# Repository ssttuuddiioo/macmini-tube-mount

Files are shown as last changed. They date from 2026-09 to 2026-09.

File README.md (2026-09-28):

# Mac mini tube mount

A 3D-printable cradle that clamps a Mac mini (127 × 127 × 50 mm) to a 1" (25.4 mm) square tube whose bottom face is velcroed down.
- **Tube velcroed down:** the Mac sits upside-down on top of it, centered, with its vented foot facing up and open.
- **Vertical tube:** the Mac hangs front-up, with the back-panel cables pointing down.

The clamp grips only the tube's two side faces, so nothing wraps around the velcro face. A small lip on the fixed side hooks 2.5 mm over one edge. Four zip-tie eyes at the corners, beside the tube, let you tie the cradle down as well; they take standard 4.8 mm ties. Four parts, all printed in PETG, with no metal hardware and no supports.

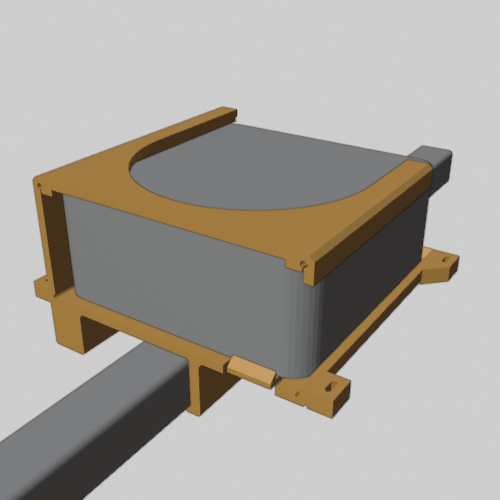
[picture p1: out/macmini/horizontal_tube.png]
Sitting on the velcroed tube


## Print

The STLs in `out/macmini/stl/` are already in print orientation, sitting on Z = 0. They were sized for a Bambu P1S (256 mm bed).

| File | Color in renders | Print orientation | Settings |
|---|---|---|---|
| `cradle.stl` | orange | front face down | 4 walls, 35% infill, brim |
| `nut.stl` | green | thread vertical | 100% infill |
| `screw_4a.stl` | yellow | wheel down | 100% infill |
| `pad.stl` | purple | grip face down | 100% infill |

Or open the ready-made plates in `out/macmini/plates/`. Each object's name lists its settings:
- `plate1_test_pieces.3mf`: the nut, a short screw stub and a 10 mm slice of the clamp. Print this first to check the thread and the tube fit. If they fit, keep the nut as a spare.
- `plate2_parts.3mf`: all four parts on one 256 mm bed.

## Assemble

1. Slide the Mac into the cradle from the front until the roof tab clicks over its front edge. The back lip stops it at the rear.
2. Drop the nut into its slot from the back of the cradle, sliding it down to the middle.
3. Thread screw 4a in from the side, through the wall and the nut, until its tip comes out on the inside. Snap the pad onto the tip.
4. Back the screw off. Hook the fixed jaw's lip under one edge of the tube, lower the cradle onto it, and tighten the screw until the pad grips the tube.
5. Optionally, run zip ties through the corner eyes to whatever the tube is mounted on.

## Rebuild from source

The geometry comes from one Blender script (tested on Blender 5.2):

```bash
blender -b --factory-startup --python build_macmini_mount.py
```

It rebuilds every part, checks fits and printability and that nothing reaches the tube's velcro face, and writes the STLs, plates and renders to `out/macmini/`. Dimensions are constants at the top of the script. For example, `RAD_CL` sets the thread clearance and `LIP_REACH` the lip size.

[NOTES_macmini.md](NOTES_macmini.md) lists the design decisions, the measured clearances, and the open issues. Check the ones about your Mac, your tube and your velcro before printing everything.

## Views

| Vertical tube | Exploded |
|---|---|
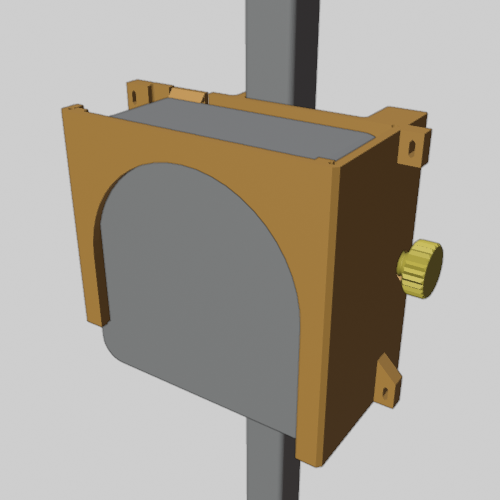
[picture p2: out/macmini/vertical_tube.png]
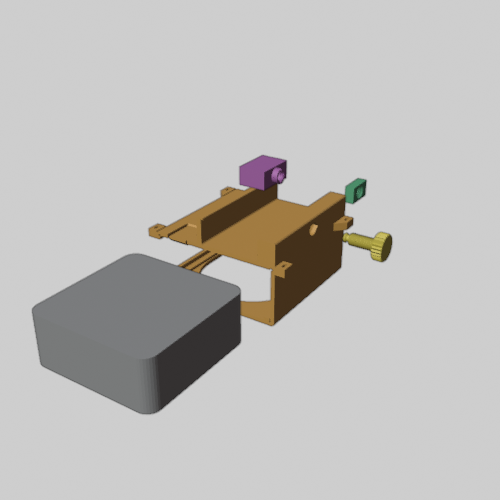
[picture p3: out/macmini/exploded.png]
|  |  |

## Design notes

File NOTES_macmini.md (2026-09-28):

# Mac mini tube mount: notes

Script: `build_macmini_mount.py`. Units: 1 BU = 1 mm. Outputs: `out/macmini_mount.blend`,
`out/macmini/*.png`, `out/macmini/stl/*.stl`, `out/macmini/plates/*.3mf`.

Four printed parts: **cradle** (orange, with the tube clamp built in), **nut** (green),
**clamp screw 4a** (yellow), **pad** (purple, the moving jaw).

## Choices

**Layout**
- The tube's bottom face is velcroed to something, so nothing may pass under it or wrap around it.
- The tube lies front-to-back on the cradle's roof, centered over the Mac, about 5 mm from the Mac's top. In use the cradle sits upside-down on the tube:
  - The Mac's weight presses the cradle onto the tube, so the clamp only has to stop sliding and tipping.
  - The Mac's vented underside faces up and stays open. Putting the tube under the floor would have blocked the vented foot.
- Vertical tube: the Mac hangs front-up, so the back-panel cables point down.
- Cradle frame: floor center at origin, Mac front faces -Y, solid side wall on +X.
- Mac clearance is 0.6 mm per side. The Mac rests on two 3 mm rails.

**Clamp (on the cradle roof)**
- Fixed jaw on -X, 5 mm thick. It grips one side face and has a 2 mm-thick lip reaching 2.5 mm over that edge of the velcro face, 0.2 mm clear of it. The lip is the only thing that passes the velcro plane.
- Abutment on +X, flush with the side wall. It holds the nut in a slot open at the back, with a 0.3 mm fit.
- Screw 4a passes through 45° teardrop clearance holes (0.6 mm radial) in the abutment walls, threads through the nut, and pushes the pad against the tube's other side face.
- Everything except the lip stops at least 1.55 mm short of the velcro plane. The closest point is the thumbwheel's top.
- The nut keeps its thread vertical when printed; a thread printed sideways in the cradle would overhang. The screw passing through it keeps it from sliding out of its slot.
- Pad: a 40 × 18 × 27.8 mm block (plus boss) spanning from the tube to the abutment. Nine 45° V-grooves on the face grip the tube. 4a's collar snaps into its socket (lip 8.2 mm over a 9.8 mm cavity, 4 slits) and spins freely.

**Threads (nut + 4a)**
- 12 mm, 2 mm pitch. This is smaller than the original 16 mm so the nut and the thumbwheel fit under the velcro plane.
- Built with the Screw modifier on a triangular profile, which worked on the first try, so no trapezoid fallback was needed.
- Buttress-like profile so it prints without supports. The lower flank is 43.7° from vertical, becoming 44.9° after the internal scale-up. The upper flank is 15° from horizontal.
- Internal thread: a radially scaled-up copy (0.35 mm at the crest), shifted 0.11 mm axially. The helix phase is locked to the screw frame so screw and nut mesh.
- The nut's hole ends get a 45° countersink down to the core.
- On the screw, the thread starts inside the root cone and stops 0.2 mm short of the neck step. Both keep the exact boolean away from coplanar faces, which otherwise leave open edges.
- Screw 4a: 26 × 10 mm knurled wheel (24 V-knurls), a 45° root cone, 24 mm of thread, then a neck and a 9 mm snap collar. The collar is small enough to pass through the nut.

**Cradle**
- Zip-tie eyes: four 10 × 14 × 8 mm tabs at the roof corners, sticking out sideways. Each has a 2.5 × 5.2 mm slot (for 4.8 mm ties) running along Z, so a tie can go past the tube to whatever it's velcroed to. Front tabs start on the print bed; back tabs have a 45° underside. The slots have pointed ends, so nothing bridges. The cradle grows from 136 to 156 mm wide.
- Floor cutout: a 112 mm circle under the foot, opened straight back to the rear edge (no ceiling when printed front-face-down).
- Power notch: 30 × 30 mm at rear-left (-X, +Y, seen from the front).
- Retention:
  - Front: a 20 × 30 mm flex tongue in the roof at x = -42, thinned to 2.4 mm, with a 3.5 mm hook.
  - Back: a 45° roof lip.
- Inside corners have 1.5 mm relief channels. Outer long edges have 2 mm chamfers.

**Test pieces**
- `test_thread.stl`: the full nut plus a 15 mm screw stub.
- `test_tube.stl`: a 10 mm slice of the clamp (fixed jaw with lip, roof, abutment with the nut slot). It's cut away from the screw holes, because a flat cut through them trips the exact boolean.

## Measured fits (posed evaluated meshes, both tube orientations)
- Thread flanks: 0.121 mm normal gap. No intersections.
- Screw in its clearance holes 0.575, collar in pad socket 0.3, nut in slot 0.3, pad to cradle 1.9 mm.
- Tube to pad 0.05, tube to fixed jaw 0.05, tube to lip 0.26 mm.
- The Mac sits 0.05 mm above the rails. That offset is only there so the fit check can tell contact apart from interference.

## Open issues
- Thread flank gap is 0.121 mm, tighter than the ~0.2 mm PETG usually likes. Print `plate1_test_pieces.3mf` first. If the thread binds, raise `RAD_CL` (radial clearance).
- Countersinks remove some partial thread at each end of the nut, so full engagement is about 7 of its 10 mm.
- Only the fixed side has a lip. The pad side holds by squeeze alone, because a lip on the pad would stop it printing flat.
- Velcro check: the lip sits 2.5 mm in from one edge of the velcro face and stands 2.2 mm proud. Your velcro must either stop at least 2.5 mm from that edge (a strip narrower than about 20 mm, centered) or be thicker than about 2.2 mm.
- The mount is designed for the velcroed-down case, where gravity seats the Mac. On a vertical tube, the clamp holds the Mac's full 0.7 kg by friction plus the lip. Check it before trusting it.
- The tube direction is fixed front-to-back.
- The fixed jaw's inner root has a 1 mm chamfer, so it needs a tube corner radius of at least 1.7 mm. Standard 1" tube is about 3 mm.
- The nut can only slide out of its slot once the screw is removed. Don't lose it while the screw is out.
- Mac assumptions to check on real hardware:
  - Power button at rear-left.
  - Foot within a 112 mm circle and less than 3 mm proud of the body.
  - Top edge radius small enough for the 3.5 mm hook to catch.
- No elephant-foot chamfer on the cradle's front (bed) edges or the pad's face edges.
- Strength under load hasn't been simulated.
- The zip-tie slots take 4.8 mm ties. Heavier ties (7.6 mm) won't fit; widen `ZIP_L` if needed.
- The tongue-slot tops are 2 mm bridges. These are the only overhangs the checker reports, and they're within the 20 mm limit.

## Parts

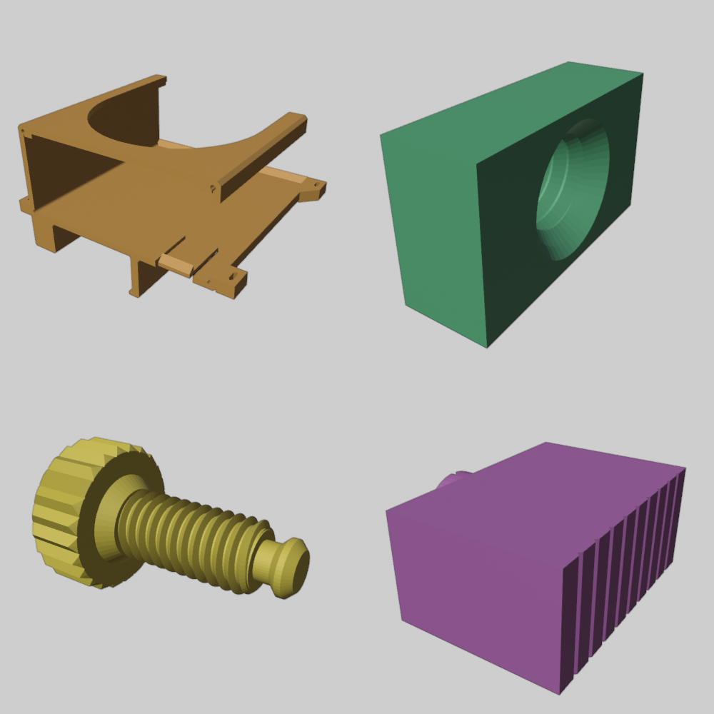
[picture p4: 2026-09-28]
out/macmini/parts_sheet.png

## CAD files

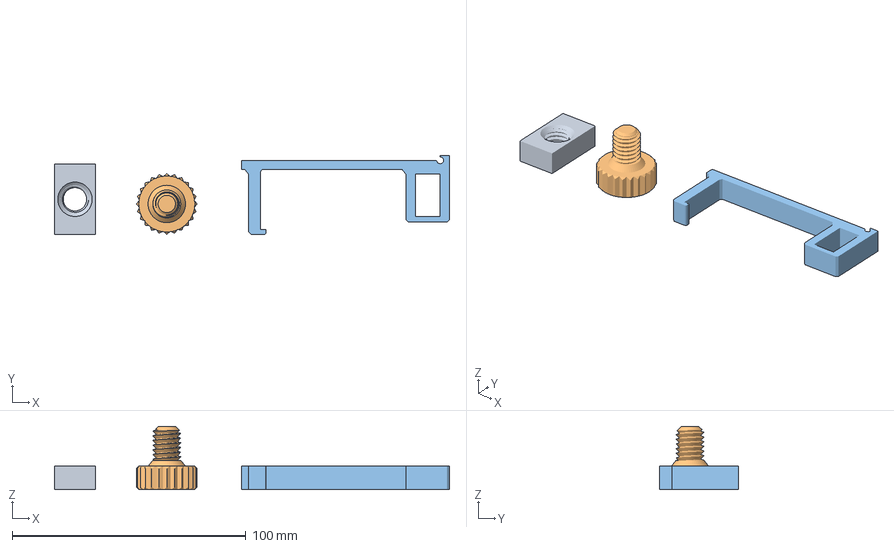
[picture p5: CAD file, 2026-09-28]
out/macmini/plates/plate1_test_pieces.3mf
168.8 x 33.7 x 27.0 mm
nut (test + spare) - 100% infill
test screw stub - 100% infill
test clamp slice - 4 walls 35% infill

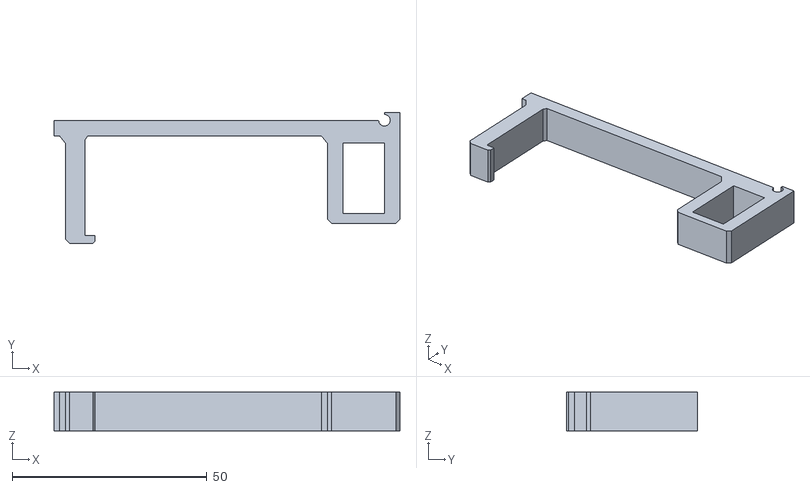
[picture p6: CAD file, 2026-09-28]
out/macmini/stl/test_tube.stl
88.8 x 33.6 x 10.0

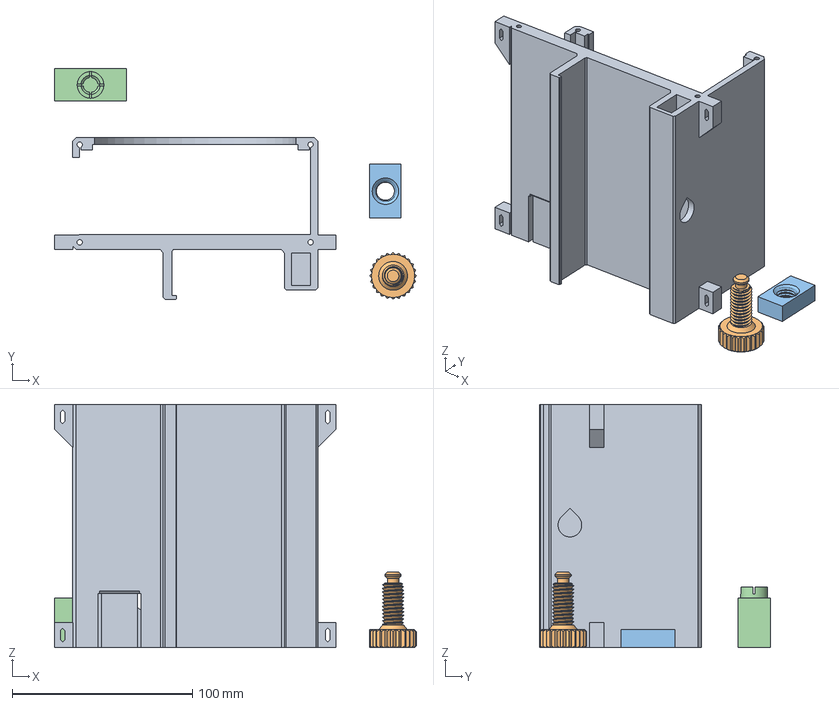
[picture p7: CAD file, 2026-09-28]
out/macmini/plates/plate2_parts.3mf
201.0 x 128.0 x 135.2 mm
cradle - 4 walls 35% infill, brim
screw_4a - 100% infill
nut - 100% infill
pad - 100% infill

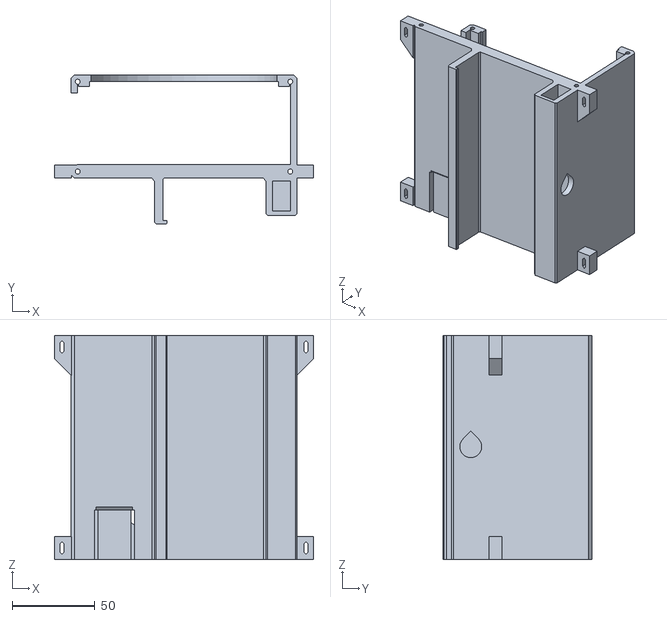
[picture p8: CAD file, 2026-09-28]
out/macmini/stl/cradle.stl
156.2 x 89.9 x 135.2

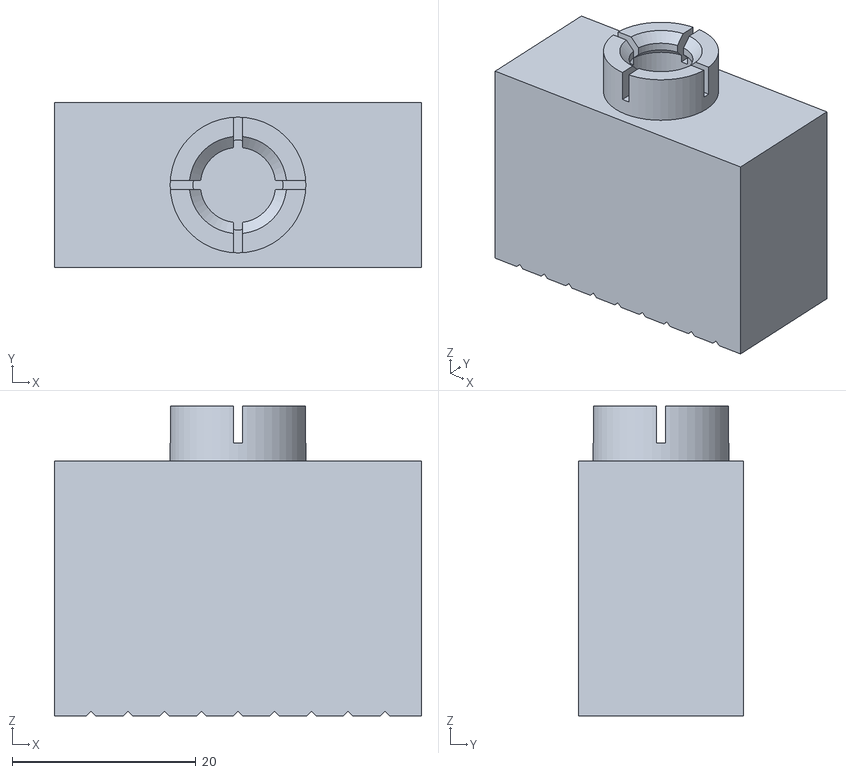
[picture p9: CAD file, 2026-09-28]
out/macmini/stl/pad.stl
40.0 x 18.0 x 33.8

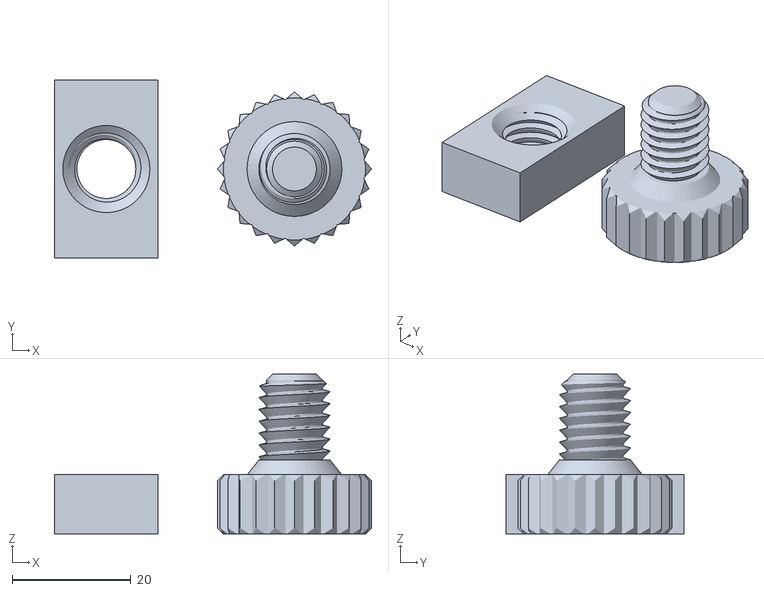
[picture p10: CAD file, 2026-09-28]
out/macmini/stl/test_thread.stl
53.5 x 30.0 x 27.0

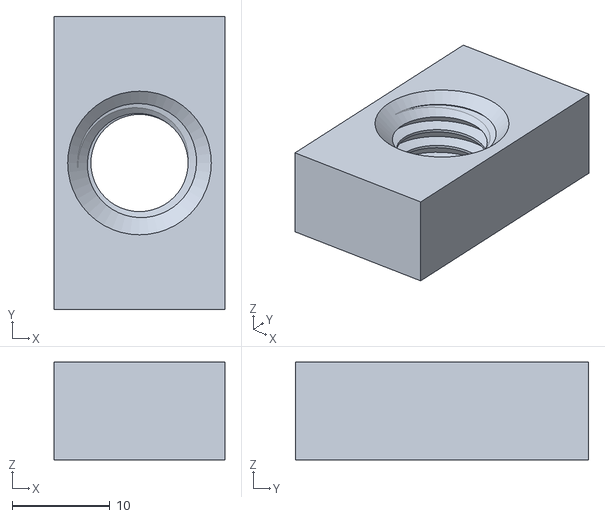
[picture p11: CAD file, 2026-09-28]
out/macmini/stl/nut.stl
17.5 x 30.0 x 10.0

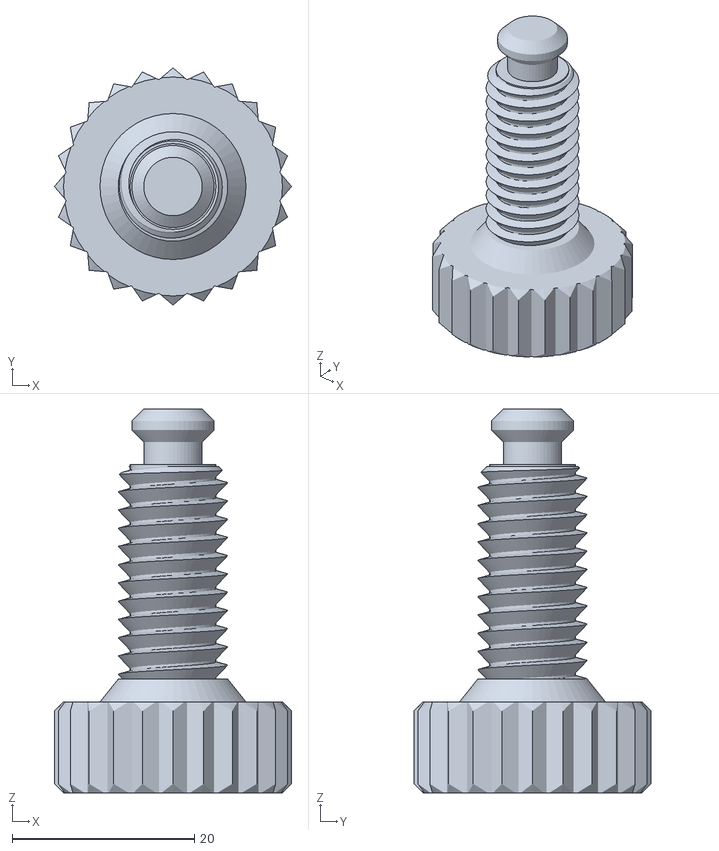
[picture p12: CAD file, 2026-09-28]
out/macmini/stl/screw_4a.stl
26.0 x 26.0 x 42.1

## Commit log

2026-09-28 Mac mini tube mount: script, notes, STLs and renders
    Printable PETG enclosure that clamps a Mac mini to a 1" square tube,
    vertical or horizontal. build_macmini_mount.py rebuilds every part in
    Blender, checks fits and printability, and writes the STLs in
    out/macmini/stl/. Split out of a larger Blender workspace, with the
    lib/ helpers it imports.
    [clamp_block.stl, cradle.stl, gate.stl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]
2026-09-28 Move the clamp connector onto the Mac's square top face
    The socket boss, socket and lock-screw hole move from the 127 x 50 side
    wall to the middle of the roof, so the clamp stacks on the Mac instead
    of beside it. On a horizontal tube the Mac hangs underneath; on a
    vertical tube it stands on edge against the tube. The cradle drops from
    170 to 136 mm wide. The snap tongue moves off-center to clear the boss.
    The connector keeps its geometry and is placed by one exact transform
    (M_CONN); a float-noisy rotation there left slivers the exact boolean
    turned into open edges. Fits, watertightness and overhang checks are
    unchanged. Other STLs only differ by float noise and cut-face
    triangulation.
    Co-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
    [cradle.stl, gate.stl, test_thread.stl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]
2026-09-28 Merge the clamp block into the cradle for a lower profile
    The tube channel is now part of the cradle: the tube lies front-to-back
    on the roof, about 7.5 mm above the Mac, in a full-length U that opens
    to the +X side. The mount drops from about 160 mm to 95 mm tall and
    from six parts to four (cradle, gate, clamp screw 4a, pad).
    Removed: clamp block, diamond tenon/socket, socket boss, lock screw 4b,
    and the zip-tie slots (through the roof they would open into the Mac).
    The tube direction is now fixed front-to-back. The tube coupon's gate
    slice moves off the threaded hole, where a flat cut trips the exact
    boolean.
    [clamp_block.stl, cradle.stl, gate.stl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]
2026-09-28 Add ready-to-print 3MF plates
    plate1_test_pieces.3mf holds both test coupons; plate2_parts.3mf lays
    out all four parts on one P1S bed. The script writes them as core-spec
    3MF, checks that every part stays on the bed with 10 mm between parts,
    and names each object with the settings it needs.
    [plate1_test_pieces.3mf, plate2_parts.3mf]
2026-09-28 Side-jaw clamp that leaves the tube's velcro face clear
    The tube is velcroed down by one face, so the clamp can no longer wrap
    around it. It now grips only the two side faces: a fixed jaw with a
    2.5 mm lip over one edge, and the pad (moving jaw) pushed by screw 4a.
    The tube is centered over the Mac, and in use the cradle sits
    upside-down on top of it, keeping the Mac's vented underside open.
    4a threads through a separate nut block that drops into a slot in the
    cradle from the back, so its thread prints vertically. The screw drops
    to 12 mm and the wheel to 26 mm so everything except the lip stays
    1.55 mm below the velcro plane, which the script now checks. The gate,
    its dovetails and the U-c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
    [cradle.stl, gate.stl, nut.stl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]
2026-09-28 Add zip-tie eyes at the cradle's four corners
    Tabs at roof level stick out sideways beside the tube, each with a
    slot for 4.8 mm zip ties, so the cradle can also be tied to whatever
    the tube is mounted on. They print without support: front tabs start
    on the bed, back tabs have a 45-degree underside, and the slots have
    pointed ends. The cradle grows to 156 mm wide; plate 2 is re-laid out.
    [cradle.stl, plate1_test_pieces.3mf, plate2_parts.3mf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]
